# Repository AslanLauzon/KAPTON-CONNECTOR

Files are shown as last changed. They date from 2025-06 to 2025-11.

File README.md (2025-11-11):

## Kapton Heater System for Oxidizer Tank Pressure Regulation

This system uses a 24V, 14.6A Kapton trace heater to regulate the pressure inside a nitrous oxide oxidizer tank, particularly in colder environments where vapor pressure drops below optimal levels. The heater is PWM-controlled via a high-current N-channel MOSFET, allowing for precise thermal regulation.



Designed by Brandon Moncriefe, Zhihan Cai and Aslan Lauzon for QRET

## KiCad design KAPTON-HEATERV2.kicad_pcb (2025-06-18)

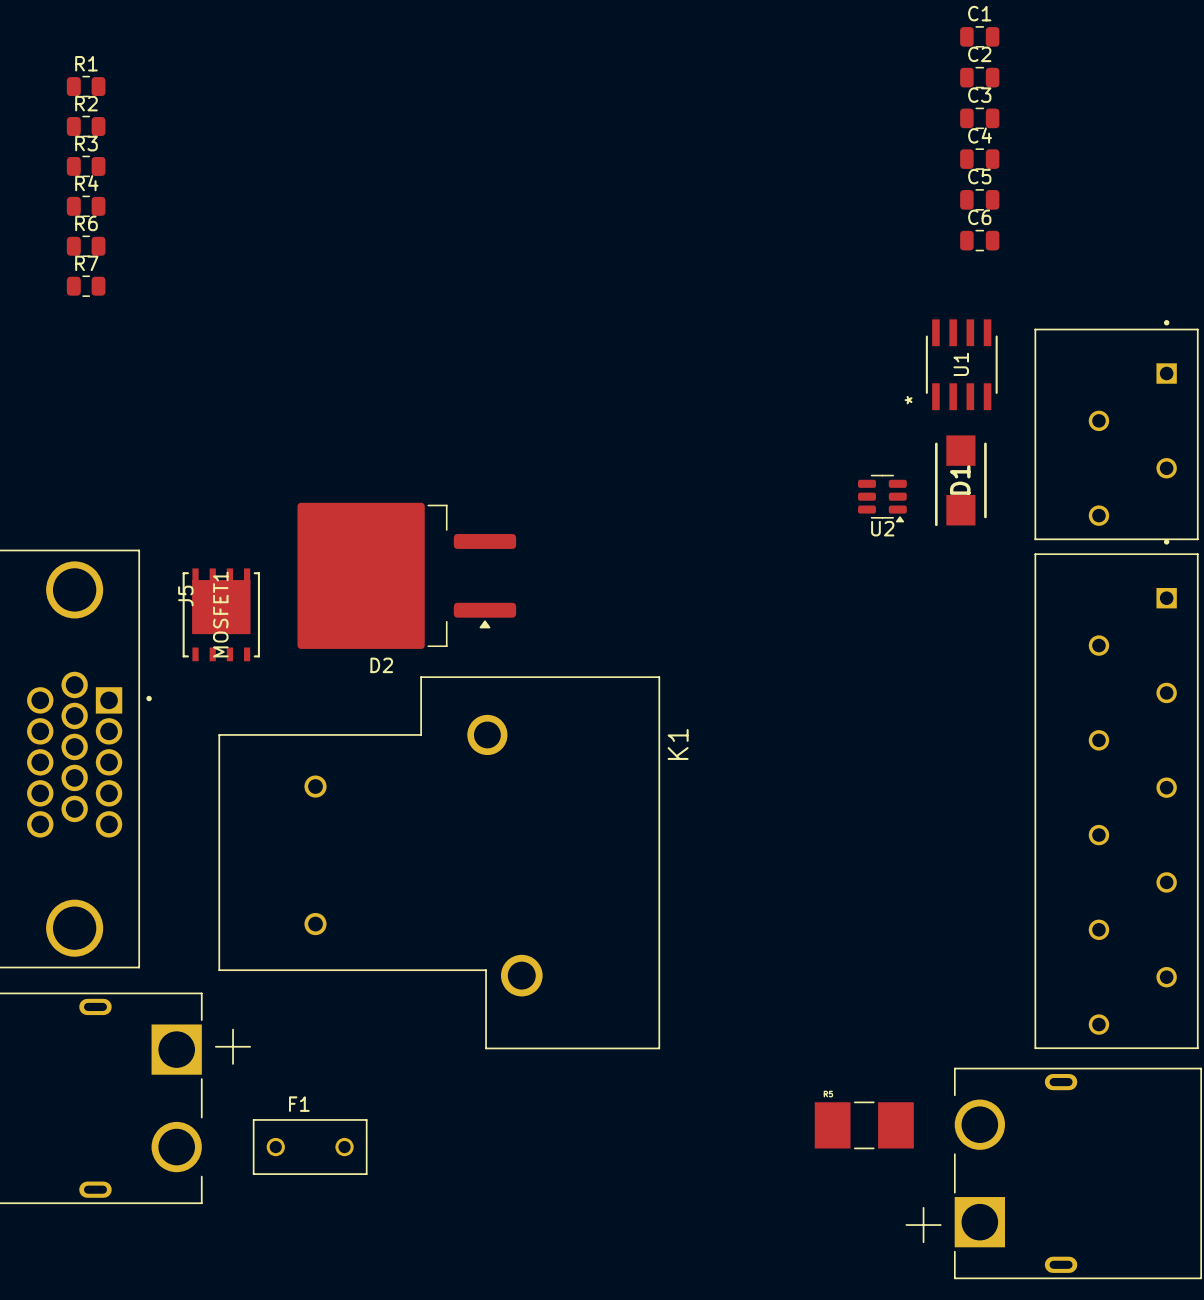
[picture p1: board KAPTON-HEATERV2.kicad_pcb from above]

Board: 2 copper layers, 25 parts (0 on the bottom side), 25 nets, no tracks yet.

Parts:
C1, C3: C4.7uf; C_0805_2012Metric
C2, C5: C0.1uf; C_0805_2012Metric
C4: C19nf; C_0805_2012Metric
C6: C0.1u; C_0805_2012Metric
D1: MBRS1100T3G; DIOM5436X247N
D2: V20DM100C-M3/I; TO-263-2
F1: 14 Amp Fuse; FUSRR508W60L835T400H810
J1, J2: XT60PW-M; AMASS_XT60PW-M
J3: 1985276; PHOENIX_1985276
J4: 1985218; TE_1985218
J5: 10090926-P154XLF; AMPHENOL_10090926-P154XLF
K1: 1-1393210-8; RELAY_1-1393210-8
MOSFET1: SIR462DP-T1-GE3; POWERPAK_SO-8_SINGLE_VIS
R1, R2: 100; R_0805_2012Metric
R3: R100k; R_0805_2012Metric
R4: 4.7k; R_0805_2012Metric
R5: R0.001; RESC6432X90N
R6: R10; R_0805_2012Metric
R7: R1k; R_0805_2012Metric
U1: TC4427ACOA; SOIC8-N_MC_MCH
U2: INA181; SOT-23-6

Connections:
5V: C3.2, C5.2, D1.1 (K), J4.4, J5.11, K1.1, U2.6 (V+)
10V: C1.1, C2.1, J4.3, U1.6 (VDD)
10V PWM: R6.2, U1.7 (OUT_A)
/24V: D2.1 (K), J1.1, K1.4
/24VIN: F1.1, J2.2
Current Vout: C6.1, J3.10, R7.1
GND: C1.2, C2.2, C3.1, C4.2, C5.1, C6.2, J2.1, J5.10, J5.S1 (SHIELD), J5.S2 (SHIELD__1), MOSFET1.1, MOSFET1.2, MOSFET1.3, R3.2, R4.2, U1.3 (GND), U1.4 (INPUT_B), U2.2 (GND), U2.5 (REF)
HEATER OUT: D2.2 (A), MOSFET1.5, MOSFET1.6, MOSFET1.7, MOSFET1.8, R5.1, U2.4 (-)
unnamed: C4.1, MOSFET1.4, R6.1
unnamed: D1.2 (A), K1.2
unnamed: R1.2, R4.1
unnamed: R7.2, U2.1
unnamed: R2.2, R3.1, U1.2 (INPUT_A)
PWM: J4.1, R2.1
RELAY: J4.2, R1.1
SHUNT HIGH: J1.2, R5.2, U2.3 (+)
TH1: J3.1, J5.1
TH2: J3.2, J5.2
TH3: J3.3, J5.3
TH4: J3.4, J5.4
TH5: J3.5, J5.5
TH6: J3.6, J5.15
TH7: J3.7, J5.14
TH8: J3.8, J5.13
TH9: J3.9, J5.12

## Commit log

2025-06-18 started new one
    [KAPTON-HEATERV2.kicad_pcb]
2025-06-18 added tvs diode
    [KAPTON-HEATERV2.kicad_sch]
